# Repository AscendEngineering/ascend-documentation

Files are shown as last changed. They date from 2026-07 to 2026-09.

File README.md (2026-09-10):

# Ascend Engineering Documentation

Source for the Ascend Engineering documentation site, published at
**<https://docs.ascendengineer.com>**.

Built with [Material for MkDocs](https://squidfunk.github.io/mkdocs-material/) from
the Markdown in [`docs/`](docs/). Pushes to `main` auto-deploy via GitHub Pages.

## Products

- **[Ascend 8tof](docs/ascend-8tof/index.md)** — 360° time-of-flight
  obstacle-sensing system (up to 8× VL53L8CX sensors on an STM32H5 carrier board):
  hardware overview, power, the UART output protocol, firmware variants, and
  integration guides (with a VOXL2 worked example), a versioned firmware/installer
  download, and complete-assembly and electronics STEP files.

More products will be added as sibling sections under `docs/`.

## Local preview

```bash
python3 -m venv .venv && source .venv/bin/activate
pip install -r requirements.txt
mkdocs serve        # http://127.0.0.1:8000
```

## Contributing

Each product is a folder under `docs/` with its own `index.md`; add a matching
section to the `nav:` in `mkdocs.yml`. Keep customer-facing content only —
integration, usage, interfaces, and specs — not internal build/manufacturing
detail.

## Versioned downloads

The 8TOF [installer guide](docs/ascend-8tof/08-install-firmware.md),
[release notes](docs/ascend-8tof/09-firmware-release-notes.md), and
[case files](docs/ascend-8tof/10-case-files.md) are linked from the product nav.
Firmware ZIPs and CAD exports live under `docs/ascend-8tof/downloads/` so MkDocs
copies them to the deployed site. Keep the ZIP checksum paired with its exact
version. The reviewable installer source is in `tools/8tof-installer/` and must
match the files inside the downloadable ZIP.

The 10 Hz / 10 ms image is a bench candidate with hardware validation pending.
Do not remove that status until the exact image has been checked on hardware.
Per-board flash backups and local installation logs are not public assets.

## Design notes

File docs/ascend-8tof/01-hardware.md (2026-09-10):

# Hardware Overview

<figure markdown="span">
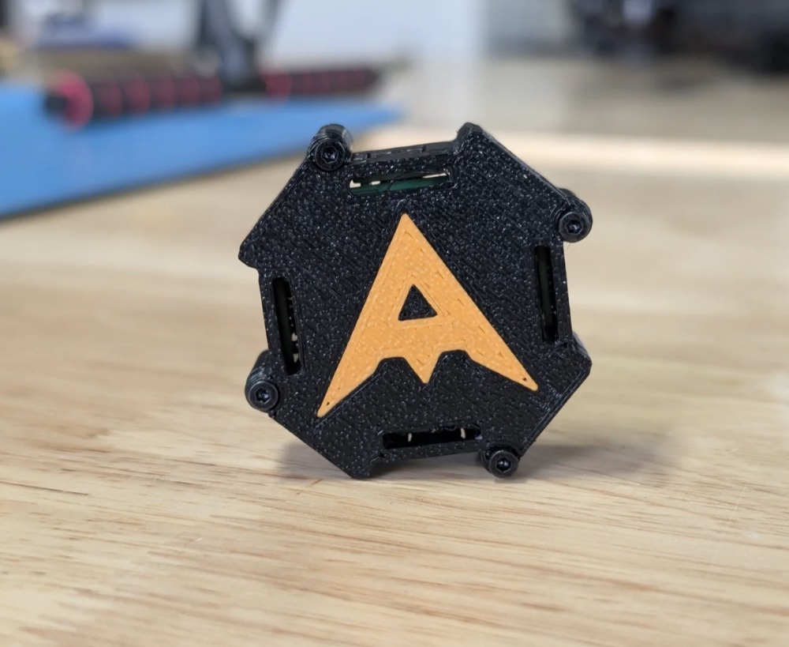
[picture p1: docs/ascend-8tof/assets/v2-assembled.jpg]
Assembled Ascend-8tof v2 in its printed case, Ascend "A" on the lid
  
  <figcaption>Assembled Ascend-8tof v2. The tip of the <strong>A</strong> marks the
  nose — the sensor behind the slot beneath it is <strong>CH7 (J8)</strong>.
  Each of the eight faces carries one VL53L8CX looking outward.</figcaption>
</figure>

The Ascend-8tof v2 is a **360° time-of-flight obstacle-sensing system** built from
two board types:

1. **Main / carrier board** — `oa_pcb_STM32H5_horizontal`, a 30 × 30 mm board
   carrying an **STM32H563RGT6**, a **TCA9548A** I²C multiplexer, onboard power
   regulation, a host UART and a SWD port.
2. **TOF sub-board (×8)** — one per channel, carrying a single **VL53L8CX** 8×8
   multizone ToF sensor. Eight plug into the main board to form the ring.

## Sensor at a glance

| Property | Value |
|---|---|
| Sensor | VL53L8CX multizone ToF |
| Zones per sensor | **8 × 8** (64 zones) |
| Sensors per board | **8** (360° coverage) |
| Ranging rate | Up to **15 Hz** at 8×8; the [candidate](09-firmware-release-notes.md) uses **10 Hz** |
| Range capability | **Up to 4 m** in suitable conditions; validate targets and lighting for the selected profile |
| Per-sensor field of view | ~45° per axis |

## Connectors & pinouts

Two externally-relevant connectors plus the eight sensor ports. **There is no
USB-C on v2** — `PA11`/`PA12` are unrouted, so all host traffic goes over `J5`.

| Connector | Type | Purpose |
|---|---|---|
| **`J5`** | JST GH 1.25 mm, 4-pin (SM04B-GHS-TB) | Power in **and** host UART |
| **`J6`** | JST GH 1.25 mm, 6-pin (SM06B-GHS-TB) | SWD — flashing and debug |
| **`J1`–`J4`, `J7`–`J10`** | 1.00 mm pin header, 1×05 | TOF sub-boards, one per channel |

<figure markdown="span">
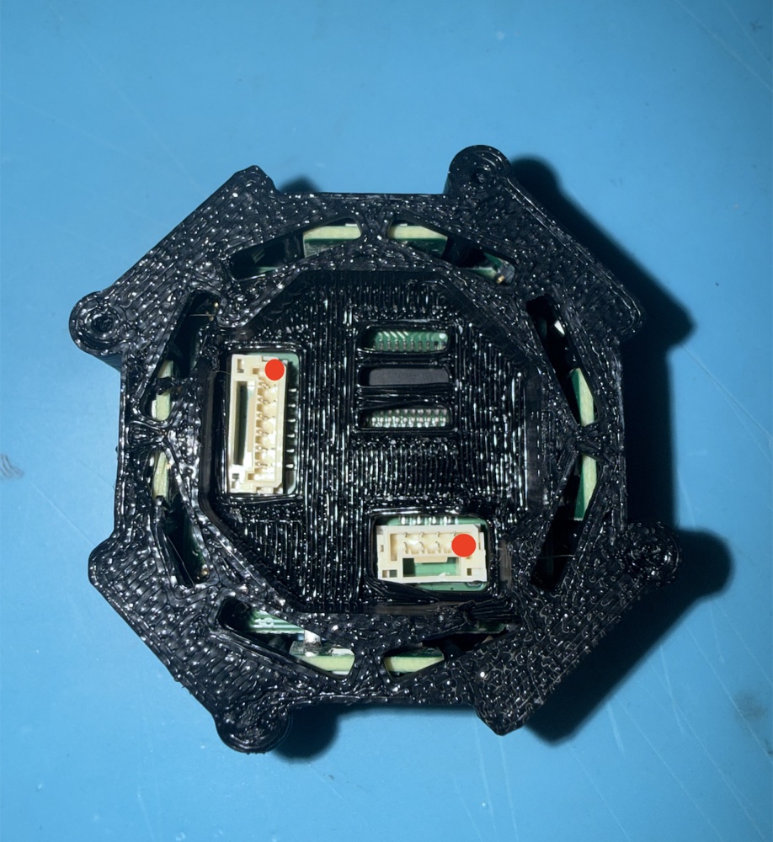
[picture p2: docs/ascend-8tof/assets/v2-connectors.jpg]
Underside of the assembled unit showing J6 (6-pin, upper left) and J5 (4-pin, lower right), each with its supply pin marked in red
  
  <figcaption>The two JST connectors, seen from the underside.
  <strong>J6</strong> (6-pin, upper left) and <strong>J5</strong> (4-pin, lower
  right). The <span style="color:#d33">red dots</span> mark the <strong>supply
  pin on each</strong> — <code>J5</code> pin 1 (<strong>VIN, 5 V</strong>) and
  <code>J6</code> pin 6 (+3V3). Use them to orient a cable before plugging it
  in: they are at opposite ends of the two connectors.</figcaption>
</figure>

**Power goes into `J5`** — the 4-pin connector, on the pin marked red. `J6` is
SWD; its +3V3 pin is a probe reference, not a way to power the board.

### `J5` — power + host UART

This single connector is both how you power the board and how you talk to it.

| Pin | Signal | Direction | Notes |
|-----|---|---|---|
| 1 | **VIN** | in | **5 V only** — see [Power](02-power.md) before wiring this |
| 2 | **RX** (`PA3`) | in | from your host's TX |
| 3 | **TX** (`PA2`) | out | to your host's RX |
| 4 | **GND** | — | must be common with the host |

!!! danger "Pin 1 is a regulated 5 V input, not a battery input"
    `J5` pin 1 feeds a 3.3 V LDO whose absolute maximum input is **6 V**, with no
    overvoltage protection in front of it. Anything above ~5.5 V risks destroying
    the board. See [Power](02-power.md).

### `J6` — SWD

| Pin | Signal |
|-----|---|
| 1 | GND |
| 2 | SWO |
| 3 | SWDIO |
| 4 | SWCLK |
| 5 | NRST |
| 6 | +3V3 |

Used for flashing firmware and for the SWD-readable diagnostics described in
[Bring-up & Setup](06-bringup-setup.md).

### Sensor connectors (×8) — 1.00 mm, 5-pin

All eight are identical. The sub-board's two supplies are generated on the
carrier board; you never provide them yourself.

| Pin | Signal |
|-----|---|
| 1 | +3V3 |
| 2 | +1V8 |
| 3 | SCL |
| 4 | SDA |
| 5 | GND |

Each connector is wired to one fixed TCA9548A channel, which fixes that
sensor's bearing in firmware:

| Channel | Connector | Bearing (CW from nose) | Direction |
|---|---|---|---|
| **CH7** | **`J8`** | **0°** | **FRONT / nose** |
| CH0 | `J4` | 45° | front-right |
| CH1 | `J3` | 90° | right |
| CH2 | `J2` | 135° | back-right |
| CH3 | `J1` | 180° | back |
| CH4 | `J9` | 225° | back-left |
| CH5 | `J10` | 270° | left |
| CH6 | `J7` | 315° | front-left |

!!! note "How the mapping is verified"
    The table above is confirmed two independent ways: the connector centroids in
    the PCB place the eight at 45° steps in the clockwise order
    `J8, J4, J3, J2, J1, J9, J10, J7`, and the TCA9548A netlist assigns its
    channel pin-pairs in the order `J4, J3, J2, J1, J9, J10, J7, J8` = CH0..CH7.
    Both agree with the physical build.

    Firmware's `tof8_sensor_bearing_deg[]` in `src/obstacle_avoidance.c` is the
    single source of truth — the browser configurator is served these exact
    values in its `INFO` message, so there is no second copy to keep in sync.

## Block diagram

```
                    ┌──────────────── carrier board (30 × 30 mm) ───────────────┐
   J5.1 VIN ──► D2 ─┼─► +5V ─► U3 ─► +3V3 ─┬─► IC1  STM32H563RGT6              │
   (5 V)      SS14  │        TLV75733      ├─► U2   TCA9548A ──┬── CH0  J4      │
                    │                      │                    ├── CH1  J3      │
   J5.2/3 UART ─────┼──── PA3 / PA2 ───────┘                    ├── ...          │
   J5.4 GND         │                                           └── CH7  J8 nose │
                    │        +3V3 ─► U1 ─► +1V8 ─► sensor pin 2                 │
   J6 SWD ──────────┼─────── TPS62130                                            │
                    └───────────────────────────────────────────────────────────┘
```

`IC1` reaches every sensor through `U2` on one I²C bus (`PB6` = SCL, `PB7` = SDA,
pulled up by `R2`/`R3`). Only one channel is connected at a time.

!!! note "U2's RESET is not under firmware control"
    `U2` pin 3 (`RESET`) connects only to pull-up `R6` — it is **not** wired to a
    GPIO. Firmware therefore cannot reset the multiplexer, and a channel
    selection can only be cleared by a **power cycle**. This matters when
    diagnosing a jammed bus; see
    [Bring-up → A sensor that jams the bus](06-bringup-setup.md#a-sensor-that-jams-the-bus).

## Dimensions & weight

| Item | Size |
|---|---|
| **Carrier board** | **30 × 30 mm** |
| **TOF sub-board** (each) | **8 × 7 mm** |
| **Assembled weight** (in case) | **15 g** |
| **Bare PCB weight** | **~9 g** |

## Mechanical / mounting

[Download the complete assembly and electronics STEP files](10-case-files.md) for
CAD reference, enclosure inspection, and mounting fit checks.

- Mount the unit flat, with the **tip of the "A" on the case lid facing the
  vehicle nose**. That puts **CH7 (`J8`) at 0°**, and the other seven follow
  clockwise at 45° steps.
- Getting this wrong rotates the entire obstacle picture, so confirm it before
  flying: open the [configurator](https://tools.ascendengineer.com), wave a hand
  at the nose, and check that **CH7**'s grid is the one that lights up.
- Sensors sit close to the vehicle centre, so mounting translation is negligible
  at meter-scale avoidance; the rotations are what matter. See
  [Integration](05-integration.md).

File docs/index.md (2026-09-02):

# Ascend Engineering Documentation

Technical documentation for Ascend Engineering hardware and software —
UAV companion computers, sensor systems, firmware, and integration guides.

<div class="grid cards" markdown>

-   :material-radar: **Ascend 8tof v2**

    ---

    360° time-of-flight obstacle-sensing system — a 30 × 30 mm STM32H563 carrier
    board reading 8× VL53L8CX sensors and emitting **MAVLink
    `OBSTACLE_DISTANCE`** straight into **stock PX4 collision prevention**, plus
    a binary 512-zone point cloud on request. Hardware, pinouts, power, comms,
    firmware, and integration (with a VOXL2 worked example).

    [:octicons-arrow-right-24: Open the Ascend 8tof docs](ascend-8tof/index.md)

-   :material-cube-outline: **More coming**

    ---

    Additional hardware and software documentation will live here as it's
    written — each product gets its own section in the left-hand navigation.

</div>

## About this site

- Every product has its own section in the sidebar (and top tabs); pick a
  product above or from the navigation to dive in.
- Documentation is maintained in the
  [`ascend-documentation`](https://github.com/AscendEngineering/ascend-documentation)
  repository; pushes to `main` auto-deploy to this site.

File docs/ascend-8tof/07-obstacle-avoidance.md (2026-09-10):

# Obstacle Avoidance — Onboard VFH + PX4 Setpoint Fusion

!!! warning "This is the `AVOID=vfh` path — not the default"
    The **default v2 firmware is `AVOID=cp`**, which emits `OBSTACLE_DISTANCE`
    into **stock PX4** and needs no custom autopilot. Start with
    [Integration](05-integration.md).

    Everything on this page requires the **Ascend PX4 fork**. Use it only if you
    need avoidance in **Mission mode**, which stock collision prevention does not
    provide.

This page explains an alternative avoidance approach for the Ascend-8tof: the board runs
the avoidance planner **on-board**, computes the *best evasive motion itself*, and
**streams velocity setpoints** to a **PX4 flight controller** that has been
extended to accept and blend them during normal flight. The drone steers around
obstacles while a mission or the pilot stays in control.

!!! note "Where this sits vs. the other firmware"
    | Approach | Who decides the maneuver | Talks to FC as | Avoids in |
    |----------|--------------------------|----------------|-----------|
    | **`AVOID=cp`** (default) | PX4 | `OBSTACLE_DISTANCE` (#330) → stock PX4 collision prevention (brake/deflect) | Position mode |
    | **`AVOID=vfh`** (this page) | The board (VFH) | `SET_POSITION_TARGET` (#84) → **forked PX4** (fuse & steer) | **Position *and* Mission** |
    | Raw point cloud | Your host | binary 512-zone frames | up to you |

    The key difference from `AVOID=cp`: instead of feeding PX4 raw obstacle distances and
    letting *its* built-in logic brake, the board computes the **actual escape
    velocity** and PX4 just executes it. This works in **Mission mode too**.

---

## The idea in one picture

```
 Ascend-8tof (STM32H5)                                   PX4 (Ascend fork)
 ─────────────────────                                   ──────────────────
 8× VL53L8CX  ─► point cloud (body frame)
                72-sector polar histogram (VFH)
                pick the best open gap
                     │                                    ┌──────────────────────┐
   path blocked? ────┤ yes ─► velocity setpoint ─MAVLink─►│ accept + FUSE the     │
                     │        SET_POSITION_TARGET  (UART)  │ setpoint in Position/ │─► drone
                     │        (#84, BODY_NED)              │ Mission mode          │   deviates
                     └ no ──► send nothing ───────────────►│ setpoint goes stale → │─► resumes
                                                           │ mission/pilot resumes │   course
   ◄── ODOMETRY (velocity/attitude) ─────────────────────  └──────────────────────┘
```

The board only speaks up **while an obstacle is in the way**. When the path is
clear it goes silent, PX4's fusion times out, and the vehicle simply carries on
with whatever it was doing — a **temporary deviation**, not a takeover.

---

## Why a forked PX4?

Stock PX4 **only accepts external `SET_POSITION_TARGET` setpoints in Offboard
mode** — a full-authority mode with no mission or pilot in the loop. That's not
what we want: we want the mission (or the pilot) to stay in charge and only be
*nudged* around obstacles.

So Ascend maintains a small PX4 fork that adds one capability: **accept an
external avoidance setpoint and fuse it into Position and Mission mode.** It's a
narrow, surgical change:

- A new uORB topic (`external_avoidance_setpoint`) carries the incoming velocity.
- The MAVLink receiver mirrors an incoming `SET_POSITION_TARGET_LOCAL_NED` onto it.
- At the single point where **both** manual (Position) and auto (Mission) flight
  tasks produce their setpoint, the fork blends the external velocity in — and
  NaNs the matching position axis so the position controller doesn't fight the
  deviation.

The board owns *all* the intelligence (sensing + planning). PX4's only job is to
**accept and blend**. If the external stream stops, PX4 reverts instantly.

---

## What the board computes (VFH)

The avoidance planner is a **Vector Field Histogram** running on the STM32 — the
same algorithm whether it's flying the real vehicle or being tested in sim:

1. **Point cloud** — the 8× 8×8 ToF grids become 3-D points in the vehicle body
   frame (roll/pitch compensated from FC attitude; floor/ceiling returns rejected).
2. **Polar histogram** — points are binned into **72 sectors** (5° each) holding
   the nearest obstacle per direction.
3. **Gap selection** — if the direction of travel is blocked, it finds the
   nearest wide-enough open gap (with hysteresis so it doesn't dither).
4. **Setpoint** — it emits a **velocity toward that gap** (default: a lateral
   *strafe* that holds heading for the fastest clearance; an optional
   *steer-to-gap* variant turns the nose instead).

This is **reactive** (no global map) and **horizontal** — ideal for "don't hit
the thing in front of me," and light enough to run on the MCU.

---

## Flight behavior

=== "Position mode"
    The pilot flies normally. When they command motion toward an obstacle, the
    board's setpoint **deflects** that motion around it. Hands-off, the drone
    simply holds — there's no goal beyond the obstacle to continue toward, so
    avoidance is naturally coupled to the pilot commanding movement.

=== "Mission mode"
    The vehicle flies its waypoints. When an obstacle blocks a leg, the board
    steers around it; the moment the path clears, PX4 resumes flying **straight
    to the active waypoint** from wherever it ended up. The mission is never
    interrupted — Ascend's fork does the deviation, PX4's navigator keeps the goal.

!!! info "After it clears the obstacle"
    The vehicle **continues on a new straight line** — to the waypoint (Mission)
    or in the pilot's commanded direction (Position). It does **not** retrace the
    exact original track; there's no cross-track "return to line" step (that's an
    optional future addition).

---

## Interface & configuration

**On the wire (board → FC):** `SET_POSITION_TARGET_LOCAL_NED` (#84),
`MAV_FRAME_BODY_NED`, velocity (± yaw-rate) active, ~20 Hz, streamed **only while
avoiding**. Same UART link as the other MAVLink firmware.

**The FC also streams back** `ODOMETRY` (#331) so the board knows the vehicle's
velocity (its "direction of travel") and attitude.

**PX4 parameters** (on the Ascend fork):

| Parameter | Default | Meaning |
|---|---|---|
| `EAV_EN` | `0` (off) | Enable fusion of the external avoidance setpoint |
| `EAV_TIMEOUT` | `0.5 s` | If no setpoint arrives within this, fusion stops and the mission/pilot setpoint resumes |

The MAVLink instance reading the board's UART must have **`forward_externalsp`
enabled** (PX4 only processes `SET_POSITION_TARGET` with it on).

---

## How it's validated — a "digital twin"

The simulation workflow exercises the firmware avoidance code in **Gazebo**:

- A simulated drone carries **8 modelled ToF sensors** (8×8, 45° FoV, 4 m).
- A bridge process **runs the real firmware algorithm unchanged**, fed by the
  simulated sensors, and streams `SET_POSITION_TARGET` to a PX4 SITL running the
  fork — the same data path as the real vehicle. Only the I/O differs (sim topics
  instead of I²C, UDP instead of UART).

The bridge uses the on-board algorithm to tune and regression-check avoidance.
Simulation results apply to the code and scenarios tested; they do not establish
physical sensor range or validate a different firmware revision. See the
[release validation status](09-firmware-release-notes.md#validation-status) for
the downloadable 10 Hz / 10 ms candidate.

---

## Status

!!! warning "In active development"
    Setpoint-streaming avoidance and the PX4 fork are **in active development**.
    Reactive/horizontal only; earlier versions were exercised in simulation and
    early flight. Start with the default **`AVOID=cp` integration** and read the
    [candidate validation status](09-firmware-release-notes.md#validation-status)
    before choosing a firmware version. Validate setpoint fusion separately on
    the intended vehicle.

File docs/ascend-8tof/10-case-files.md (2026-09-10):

# Case and assembly files

Download the v2 complete-assembly and electronics STEP files for enclosure fit
checks, mounting, and CAD reference. Both exports are preserved as supplied.
The electronics STEP replaces the previously supplied assembly STL download.

| Download | Format | Size | Intended use |
|---|---|---|---|
| [Complete assembly — STEP](downloads/case/tof8_v2_COMPLETE_assembly.step) | STEP / AP214 | 7.34 MiB | Inspect the complete assembly and select enclosure components |
| [Electronics assembly — STEP](downloads/case/tof8_v2_electronics.step) | STEP / AP214 | 4.19 MiB | Inspect the electronics assembly and check enclosure clearances |
| [File checksums](downloads/case/SHA256SUMS) | SHA-256 | — | Confirm downloads match the supplied exports |

Assembled v2 case with the forward-facing A

The tip of the **A** on the lid faces the vehicle nose, aligned with **CH7/J8**.
Use the [hardware overview](01-hardware.md#mechanical-mounting) for connector
orientation and the [bring-up guide](06-bringup-setup.md) to verify it with a
real target.

## Using the files

- Both STEP files declare **millimetres** and contain multiple solids. Import
  them as assembly/reference models; check your CAD program's unit settings.
- Use the complete-assembly export to inspect the case and select the enclosure
  components you need. Use the electronics export to reference board and
  component placement when checking clearances.
- Select and export individual enclosure pieces for your slicer before preparing
  a print. These downloads do not include verified print orientation, supports,
  tolerances, or material settings.

Both STEP headers/terminators, unit declarations, and checksums were checked.
These checks establish file integrity; mechanical fit and print readiness still
require inspection and a physical fit check. The documentation update does not
modify either file's geometry.

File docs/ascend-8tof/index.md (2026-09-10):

# Ascend-8tof v2 — System Documentation

Documentation for the **Ascend-8tof v2** 360° time-of-flight obstacle-sensing
system: a 30 × 30 mm carrier board (STM32H563) reading **8× VL53L8CX** 8×8
multizone ToF sensors and speaking **MAVLink** to a flight controller over a
single UART.

```
 8× VL53L8CX ──► carrier board ──┬── MAVLink OBSTACLE_DISTANCE ──► PX4 collision prevention
  (8×8 grids)   (mux + STM32H5)  │   (always on)
                                 └── 512-zone point cloud ──────► configurator / your host
                                     (on request)
```

## Downloads

- [Firmware and installer](08-install-firmware.md) — 10 Hz / 10 ms bench candidate;
  read the [validation status](09-firmware-release-notes.md#validation-status).
- [Case and assembly STEP files](10-case-files.md).

## Documentation map

| # | Document | Contents |
|---|---|---|
| 01 | [Hardware Overview](01-hardware.md) | Board, connectors & pinouts, channel map, mounting |
| 02 | [Power](02-power.md) | Input voltage limits and how to power it |
| 03 | [Communications](03-comms-protocol.md) | MAVLink output and the binary point-cloud link |
| 04 | [Firmware](04-firmware.md) | Build variants, flashing, diagnostic builds |
| 05 | [Integration](05-integration.md) | PX4 collision prevention + VOXL2 worked example |
| 06 | [Bring-up & Setup](06-bringup-setup.md) | Assemble → power → verify → integrate → troubleshoot |
| 07 | [Obstacle Avoidance (onboard VFH)](07-obstacle-avoidance.md) | The alternative `AVOID=vfh` path, needing the Ascend PX4 fork |
| 08 | [Install Firmware](08-install-firmware.md) | Prebuilt download, ST-Link setup, installer, and rollback |
| 09 | [Firmware Release Notes](09-firmware-release-notes.md) | 10 Hz / 10 ms candidate, measurement behavior, validation status |
| 10 | [Case & Assembly Downloads](10-case-files.md) | Complete assembly and electronics STEP exports |

## Key facts at a glance

- **Sensors:** 8× VL53L8CX, each an **8×8 zone grid**, configurable up to **15 Hz**, forming a 360° ring.
- **Range capability:** up to 4 m under suitable conditions; usable range depends
  on lighting, target, and profile. ~45° field of view per axis.
- **Power:** **5 V only** on `J5` pin 1; current depends on the ranging profile — see [Power](02-power.md).
- **Host link:** one UART at **921 600 8N1** carrying MAVLink (always) and the
  point cloud (on request).
- **Default output:** `OBSTACLE_DISTANCE` (#330) at 10 Hz, 72 bins × 5°, straight
  into **stock PX4 collision prevention** — no custom autopilot build.
- **Mounting:** the tip of the **A** on the lid is the nose = **CH7 (`J8`)**.
- **Configurator:** <https://tools.ascendengineer.com> — live 3D cloud and zone
  masking in Chrome.

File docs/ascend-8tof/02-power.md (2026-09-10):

# Power

v2 takes a **single 5 V input** on `J5` pin 1 and generates the sensor rails
on-board. You never supply sensor voltages yourself.

!!! danger "5 V only"
    There is **no wide-input regulator.** `J5` pin 1 feeds a 3.3 V LDO directly
    through a series Schottky diode. Wiring a flight battery to it will destroy
    the board.

## Input

| Parameter | Value |
|---|---|
| **Input voltage** | **5 V nominal** |
| **Maximum** | **~5.5 V** — see the limit below |
| Connector | `J5` pin 1 (JST GH 1.25 mm, 4-pin) — [which pin, in a photo](01-hardware.md#connectors-pinouts) |
| Ranging current | Profile and load dependent; measure at the regulated 5 V input |
| Peak current | brief inrush at power-on as all eight sensors initialise |
| Protection | **reverse polarity only** (`D2`, SS14 Schottky in series) |

### Where the limit comes from

The supply chain is short and has no headroom above 5 V:

```
J5.1 ──► D2 (SS14, series Schottky) ──► +5V ──► U3 (TLV75733) ──► +3V3
                                                                    │
                                                                    └─► U1 (TPS62130) ──► +1V8
```

`U3` is a **TLV75733** 3.3 V LDO whose input is rated **5.5 V recommended,
6 V absolute maximum**. Nothing upstream of it clamps or regulates — `D2` is a
plain series diode that only blocks reverse polarity and drops roughly 0.3–0.4 V.
So the LDO sees very nearly whatever you apply to `J5` pin 1.

`U1` (TPS62130) is a wide-input buck, but it is **not** the input stage: it runs
from the 3.3 V rail to produce the sensors' 1.8 V. It does not protect the input.

!!! warning "There is no overvoltage protection"
    `D2` blocks reverse polarity and nothing else — any positive voltage passes
    straight through to a 6 V-max part. This is a known limitation of the current
    revision and is on the list for the next one. Until then, **feed `J5` from a
    regulated 5 V rail**, and check with a meter before plugging in an unfamiliar
    supply.

## Powering it

| Situation | How |
|---|-----|
| **Bench** | A USB-UART adapter's 5 V/VCC pin into `J5` pin 1, with its TX/RX/GND on pins 2/3/4. One cable does power and data. |
| **On a vehicle** | A regulated **5 V** rail from the flight-control unit or power module into `J5` pin 1. |

Because `J5` carries power and UART on the same connector, a single 4-wire lead
is all the integration needs. See [Bring-up & Setup](06-bringup-setup.md).

## What the board provides

- Both sensor supplies (**+3V3** and **+1V8**) are generated on-board and
  distributed through the eight sensor connectors.
- `J6` pin 6 is **+3V3**. It is there so a debug probe can sense target voltage —
  do not use it to power the board.

## Choosing a ranging profile

The [10 Hz / 10 ms candidate](09-firmware-release-notes.md) collects more light
per measurement than the earlier 15 Hz / 5 ms experiment, at a longer frame
interval. An 8×8 frame uses four sub-integrations:

| Profile | Exposure per frame | Calculated exposure duty |
|---|---:|---:|
| 15 Hz / 5 ms | 20 ms | 30% |
| **10 Hz / 10 ms candidate** | **40 ms** | **40%** |
| 15 Hz / 10 ms | 40 ms | 60% |

Exposure duty is not total board power. Sensor processing, MCU activity, the
UART stream, and losses in the input diode and 3.3 V LDO also contribute.
Keep voltage, connected peripherals, and scene fixed when comparing input
current/watts. Check reliable detections at known distances indoors and in
daylight; dashboard frame rate alone does not establish range or accuracy.

The candidate's power and range have not yet been measured. Shortening
integration can save power but makes weak reflections harder to detect.
[ST integration timing](https://www.st.com/content/st_com/en/technical-documents/UM3109.html).

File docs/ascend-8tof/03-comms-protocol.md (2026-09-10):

# Communications — UART Protocols

`J5` is v2's only host connector, and it carries **two protocols at once** at
**921 600 baud, 8N1**:

| Protocol | Direction | When it runs |
|---|---|---|
| **MAVLink v2** | board → host (and host → board) | **always, unconditionally** |
| **Point-cloud link** (`0xA5 0x5A` framed) | board → host, on request | **only while a host asks for it** |

## Why a passive listener sees only MAVLink

This is the single most common surprise on v2, and it is deliberate.

`J5` is the board's only UART, so it has to serve both the flight controller and
the configurator. Rather than a mode switch — which could leave a vehicle flying
with avoidance disabled if it ever got stuck — **MAVLink always runs**, and only
the high-rate point cloud is gated:

- Any valid point-cloud command received from a host **arms** streaming and
  refreshes a deadline (`UART_LINK_GATE_MS`, 3 s).
- When the host stops talking, the deadline lapses and the cloud stops on its own.
- **At boot the gate is shut.**

So on the bench with a configurator attached you get the full cloud, and in
flight with nothing attached the link carries only MAVLink. Avoidance is never
suspended either way.

**The practical consequence:** you cannot sniff the point cloud. You have to ask
for it and keep asking, roughly once a second. If you are seeing MAVLink and no
`0xA5 0x5A` frames, that is the gate, not a fault.

Receive needs no gating — the USART2 interrupt mirrors every incoming byte to
both parsers, and each ignores what it does not recognise (MAVLink syncs on
`0xFD`, the point-cloud link on `0xA5 0x5A`, and both are CRC-checked).

## MAVLink output

What the board emits depends on the firmware variant (see
[Firmware](04-firmware.md)):

| Message | ID | Rate | Variant |
|---|-----|---|---|
| `HEARTBEAT` | 0 | 1 Hz | all |
| `OBSTACLE_DISTANCE` | **330** | **10 Hz** | `AVOID=cp` (default) |
| `SET_POSITION_TARGET_LOCAL_NED` | 84 | — | `AVOID=vfh` |

The board also *parses* `ODOMETRY` (331) and `ATTITUDE_QUATERNION` (31) coming
back from the flight controller, and uses the attitude for tilt compensation.

### `OBSTACLE_DISTANCE` field values

These values describe the [10 Hz / 10 ms candidate](09-firmware-release-notes.md).
Older firmware can use different minimum-range and unknown-data behavior;
confirm the installed version before relying on these semantics.

| Field | Value |
|---|---|
| `frame` | `MAV_FRAME_BODY_FRD` (12) |
| `sensor_type` | `MAV_DISTANCE_SENSOR_LASER` (0) |
| `increment_f` | **5.0°** |
| `angle_offset` | **2.5°** (bin centres, not edges) |
| `distances[]` | **72 bins**, centimetres |
| `min_distance` | **2 cm** in the candidate (older builds used 50 cm) |
| `max_distance` | **400 cm** |

Two sentinel values matter:

- **`401` (`max_distance + 1`)** means no obstacle within the advertised range.
  The candidate does **not** generate this from a missing echo or geometric
  coverage alone.
- **`65535` (`UINT16_MAX`)** means **unknown / not used**. The candidate uses it
  for weak, missing, masked, expired, and unmeasured directions.

An accepted measurement provides an obstacle distance, with the nearest return
winning in each bin. Samples expire 200 ms after their successful polling pass.
PX4 may restrict motion into unknown directions; do not enable `CP_GO_NO_DATA`
merely to hide missing measurements. The 400 cm field is the configured maximum,
not a guarantee of reliable 4 m detection under every lighting/target condition.

## Point-cloud link

The binary protocol the browser configurator speaks, carrying the **raw,
unmasked** 512-zone cloud plus the read/write path for the persistent zone mask.

### Framing

```
0xA5 0x5A  <type:u8>  <len:u16 LE>  <payload[len]>  <crc16:u16 LE>
```

CRC-16/MCRF4XX ("X.25") over `type + len + payload`. The two-byte sync word plus
the CRC lets a host that connects mid-stream resynchronise unambiguously, and
lets it skip the interleaved MAVLink bytes.

### Message types

| Direction | ID | Name | Payload |
|---|-----|---|---|
| board → host | `0x01` | `INFO` | geometry: sensor count, grid size, per-channel bearings, mask sequence |
| board → host | `0x02` | `FRAME` | the full 512-zone cloud (below) |
| board → host | `0x03` | `MASK` | current 512-byte zone mask |
| board → host | `0x04` | `ACK` | reply to a host command |
| board → host | `0x05` | `DIAG` | why bring-up failed, per channel |
| host → board | `0x81` | `GET_INFO` | — |
| host → board | `0x82` | `GET_MASK` | — |
| host → board | `0x83` | `SET_MASK` | 512 gate bytes (RAM only) |
| host → board | `0x84` | `SAVE_MASK` | persist RAM mask to flash |
| host → board | `0x85` | `STREAM` | `u8` enable |
| host → board | `0x86` | `GET_DIAG` | — |

Any of the host → board messages re-arms the 3 s gate, so `GET_INFO` doubles as
a keepalive.

### `FRAME` payload

1554 bytes: an 18-byte header followed by eight fixed-size sensor blocks.

| Offset | Size | Field |
|---|---|---|
| 0 | u32 | `seq` |
| 4 | u32 | `timestamp_ms` |
| 8 | u8 | `sensor_valid` — bit *n* = channel *n* has data this frame |
| 9 | u8 | `odom_valid` |
| 10 | i16 | `roll_cdeg` |
| 12 | i16 | `pitch_cdeg` |
| 14 | i16 | `yaw_cdeg` |
| 16 | u16 | reserved |
| 18 | 8 × 192 | per-sensor block |

Each sensor block is **64 little-endian u16 ranges in mm**, then **64 status
bytes**. Channels with no data are sent as zeroes so the payload stays
fixed-size and a host can index it without parsing.

!!! note "Only status 5 and 9 are real measurements"
    Every other status is a no-return. Treat those zones as **no data** — never
    as "obstacle at 0 mm". `FRAME` deliberately carries the *unmasked* cloud so
    the configurator can show you what a mask would discard; everything
    downstream of this link (the planner, the MAVLink output) sees the masked
    cloud.

## Reading it

The supported tools live in the firmware repo:

```bash
# stream the raw 8×(8×8) matrices — handles the keepalive for you
python3 tools/tof8-stream.py                        # live grids
python3 tools/tof8-stream.py --format jsonl         # one JSON object per frame
python3 tools/tof8-stream.py --format csv -o cloud.csv

# link health / which channels are ranging
python3 tools/tof8-poll.py
```

Both are standard-library only (no `pyserial`) and run on Python 3.6, so they
work on a stock VOXL2 image.

!!! warning "One process owns the port"
    A serial port has one owner. If the configurator tab, `screen`, or
    `mavlink-router` holds `J5`, these tools cannot. On a VOXL2, `/dev/ttyHS1` is
    already owned by PX4's `mavlink` instance — two readers on one tty do not each
    get a copy, they race and both get a corrupted subset. `tof8-stream.py` warns
    when another process already holds the device.

## Graphical configurator

<https://tools.ascendengineer.com> — a browser tool (Chrome, via Web Serial) that
draws the live cloud in 3D and lets you paint and save the zone mask. It speaks
exactly the protocol above and keeps the gate open with a ~1 Hz keepalive.

Web Serial requires a **secure context**, so the tool must be loaded over HTTPS.

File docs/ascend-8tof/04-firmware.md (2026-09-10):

# Firmware

## Prebuilt firmware and installer

The [2026.09.10-10hz10ms download](08-install-firmware.md) is a **bench candidate**
for the horizontal v3 carrier with eight v2 sensor boards. It uses 8×8 zones,
10 Hz per sensor, 10 ms sub-integration, `AVOID=cp`, and 180° zone orientation.
It also corrects weak/invalid readings being reported as clear space.

The package includes its installer and offline instructions. No source checkout
or compiler is needed. Read the [release notes](09-firmware-release-notes.md)
and [pending hardware-validation status](09-firmware-release-notes.md#validation-status)
before using it.

## Source builds

The firmware codebase is
[`AscendEngineering/ascend-8tof`](https://github.com/AscendEngineering/ascend-8tof).
Source builds select a board variant and an avoidance output. Use the versioned
package for the candidate above; a checkout of the firmware repository is not
proof that it contains every change in that prebuilt image.

```bash
make BOARD=horiz3 AVOID=cp          # source default profile; not the versioned candidate installer
```

## Board variant — `BOARD=`

Always build with **`BOARD=horiz3`** (`oa_pcb_STM32H5_horizontal`). It selects the
single-UART configuration: `J5` carries MAVLink *and* the gated point cloud.

!!! warning "`BOARD=` does not default to this board"
    The Makefile's default targets a different variant, so omitting `BOARD=horiz3`
    silently builds an image that will not work here. Pass it every time — or use
    `tools/flash-board.sh`, which sets it for you.

## Avoidance output — `AVOID=`

This selects what goes on the MAVLink wire. The point-cloud link is unaffected.

| Value | Emits | Who avoids | Requires |
|---|---|---|---|
| **`cp`** (default) | `OBSTACLE_DISTANCE` (#330) at 10 Hz | **stock PX4** collision prevention | `CP_DIST > 0` on the FC |
| `vfh` | `SET_POSITION_TARGET_LOCAL_NED` (#84) | the **board**, running VFH+ | the Ascend PX4 fork |
| `both` | both | — | bench comparison only |

!!! warning "`AVOID=both` is not a flight configuration"
    On a fork that honours #84, the two controllers fight over the same axis.
    Use it to compare behaviour on the bench, never on a vehicle.

`AVOID=cp` is the one to use unless you are specifically working on the fork —
it needs no custom PX4. See
[Obstacle Avoidance](07-obstacle-avoidance.md) for the `vfh` path and
[Integration](05-integration.md) for the `cp` path.

## Diagnostic and repair builds

These exist for bring-up and board repair. They are not flight builds.

| Option | Purpose |
|---|---|
| `DIAG=1` | Cold-boot I²C bus walk — finds a sensor that jams the bus |
| `DIAG=1 DIAGDIR=down` | The same walk in descending channel order |
| `EXCLUDE=4` | Permanently skip mux channel 4 (comma-separate for several) |

`EXCLUDE=` can isolate a known-bad sensor during diagnosis: the excluded
channel is never selected, so one failed part cannot take the other seven down
with it. See
[Bring-up → A sensor that jams the bus](06-bringup-setup.md#a-sensor-that-jams-the-bus).

Each combination builds into its own directory (`build/horiz3-cp`,
`build/horiz3-cp-ex4`, …) so a diagnostic image is never mistaken for a flight
image.

## Flashing

For the downloadable candidate, follow [Install Firmware](08-install-firmware.md).
It checks package integrity, backs up flash, verifies the image and sensor
profile, and checks saved masks. The commands below are the firmware
repository's older source-build workflow, not the packaged installer.

v2 has no USB and no bootloader button — **firmware goes on over SWD** via `J6`
with an ST-Link.

```bash
AVOID=cp BOARD=horiz3 ./tools/flash-board.sh
```

The script identifies the chip, flashes, waits for bring-up and prints the
per-channel result:

```
firmware  : build/horiz3-cp/ascend-horiz3-fw.elf
board UID : 00520036
** Programming Finished **
** Verified OK **
uptime    : 12.6 s
sensors   : 8/8
result    : ALL 8 CHANNELS OK
```

!!! note "A reset is not a power cycle"
    The script's post-flash reading happens after a **reset**, which does not
    clear the TCA9548A's channel latch. A board whose bus was jammed before
    flashing will still report `0/8` afterwards even if it is fine. Power-cycle
    it and re-check with `./tools/read-sensors.sh`, which reads a running board
    without resetting it.

## Ranging and measurement behavior

- The sensors support up to **15 Hz** at 8×8; older builds use that rate. The
  downloadable candidate explicitly selects **10 Hz / 10 ms**.
- The persistent zone mask applies to avoidance processing. The browser receives
  the raw cloud so users can see and edit the returns being excluded.
- `AVOID=cp` sends `OBSTACLE_DISTANCE` at 10 Hz, independently of the sensor
  rate. A faster browser packet counter is not a faster sensor measurement rate.
- The candidate reports weak, missing, masked, expired, and unmeasured directions
  as **unknown**. It retains close valid obstacles instead of discarding all
  measurements below 50 cm, and expires cached samples after 200 ms.
- Initialization retries and per-channel recovery exist in the source. The
  candidate reapplies its selected profile during recovery; physical recovery
  fault injection remains unverified. A stuck I²C bus can still require a
  power cycle or hardware repair.

See [release notes](09-firmware-release-notes.md) for the exact changes and
validation limits. These descriptions do not imply every older board already
has the candidate installed.

## Persistent zone mask

Zones can be permanently excluded — propellers, landing gear, the vehicle's own
frame. The mask is painted in the [configurator](https://tools.ascendengineer.com)
and saved to flash with `SAVE_MASK`.

It is stored in the **last two 8 KB sectors of bank 2** as alternating A/B slots
with a CRC and a sequence number, so an interrupted write can never destroy the
config currently in use. Firmware loads it before the first frame is served.

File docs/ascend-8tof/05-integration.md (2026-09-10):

# Integration

With the default `AVOID=cp` firmware, v2 speaks **stock MAVLink** to a stock
PX4. There is no plugin to install and no custom autopilot build: the board
emits `OBSTACLE_DISTANCE` (#330) and PX4's built-in collision prevention does
the avoiding.

## Wiring

| Board | Host |
|---|---|
| `J5` pin 3 (TX) | host RX |
| `J5` pin 2 (RX) | host TX |
| `J5` pin 4 (GND) | host GND |
| `J5` pin 1 | regulated **5 V** |

Both data directions must be connected. The board needs attitude back from the
flight controller for tilt compensation, and the point-cloud link is gated on
hearing from a host at all.

## PX4 collision prevention

### 1. Give PX4 a MAVLink instance on that port

The board sends #330 at 10 Hz and needs `ODOMETRY` back. On a VOXL2, add this to
`/usr/bin/voxl-px4-start` **before** `mavlink boot_complete`:

```bash
# 8TOF obstacle array on /dev/ttyHS1. Sends OBSTACLE_DISTANCE (#330) for PX4
# collision prevention, and needs attitude back for tilt compensation.
# -m minimal, not onboard: the board only parses ODOMETRY (#331) and
# ATTITUDE_QUATERNION (#31), so a full onboard stream set is wasted bandwidth.
mavlink start -d /dev/ttyHS1 -b 921600 -m minimal -r 2000
mavlink stream -d /dev/ttyHS1 -s ODOMETRY -r 30
```

On other autopilots, point any spare TELEM port at the board at **921 600** and
make sure `ODOMETRY` is streamed back.

### 2. Set the parameters

| Parameter | Value | Why |
|---|---|-----|
| `CP_DIST` | **> 0** (e.g. `1.5`) | Gates collision prevention entirely. At `-1` it is off and nothing else matters. |
| `MPC_POS_MODE` | **see below** | Determines whether the active flight task even *has* collision prevention. |
| `CP_GO_NO_DATA` | `0` (default) | Whether to allow movement into bins with no data. |

!!! danger "`MPC_POS_MODE` depends on your PX4 version"
    Collision prevention lives in a different flight task depending on release,
    and setting the wrong one produces a vehicle that flies happily through
    obstacles with no error message:

    | PX4 | Where CP lives | Working `MPC_POS_MODE` |
    |-----|----------------|------------------------|
    | **1.14** | `FlightTaskManualPosition` (and `…SmoothVel`) | **3** |
    | **1.18** | `StickAccelerationXY` | **4** |

    On 1.14, `MPC_POS_MODE=4` selects `FlightTaskManualAcceleration`, whose
    `StickAccelerationXY` has **no** collision prevention at all. Check the
    firmware version on the vehicle before trusting any guide — including this
    one.

Collision prevention is **position-mode only**. It does not act in altitude or
manual mode, and mission avoidance is a separate feature.

### 3. Verify PX4 is receiving it

```bash
listener obstacle_distance
```

You want a recent timestamp and a populated `distances` array. `never published`
means the messages are not arriving — check baud, wiring direction, and that the
`mavlink` instance is actually running on that device.

On a VOXL2 note the split architecture: `mavlink` runs on the **apps processor**
while `commander`, `flight_mode_manager` and `mc_pos_control` run on the **SLPI
DSP**. The topic crosses a `muorb` bridge, so check the subscriber count on the
DSP side too — a topic published on apps with zero DSP subscribers will look
alive and still do nothing.

### What "clear" and "unknown" mean

For the [10 Hz / 10 ms candidate](09-firmware-release-notes.md):

- **`401` cm** is the MAVLink value for no obstacle within the advertised range.
  The candidate does not infer it from a missing echo.
- **`65535`** is unknown, including weak/no-target returns, masked zones,
  expired samples, and unmeasured directions.
- Other accepted values are measured obstacle distances. Valid close returns
  are retained, including those below the older firmware's 50 cm cutoff.

Unknown can cause PX4 Collision Prevention to restrict movement. Do not set
`CP_GO_NO_DATA` merely to bypass missing measurements. Validate the installed
firmware's behavior with real targets before using it for collision prevention.
See [wire fields](03-comms-protocol.md#obstacle_distance-field-values).

## Reading the raw cloud on a host

If you want the 512-zone cloud rather than (or as well as) avoidance:

```bash
python3 tools/tof8-stream.py --format jsonl     # one JSON object per frame
python3 tools/tof8-stream.py --format csv -o cloud.csv
```

Standard library only, Python 3.6+, so it runs on a stock VOXL2 image. See
[Communications](03-comms-protocol.md#point-cloud-link) for the wire format if
you are writing your own parser.

!!! warning "You cannot share the port with PX4"
    A tty has one owner. If PX4's `mavlink` holds `/dev/ttyHS1`, a second reader
    does not get a copy — they race, and both get a corrupted subset. Stop the
    `mavlink` instance on that device first, or read the board from a separate
    machine over a USB-UART adapter.

## Geometry, if you are building your own consumer

For an 8×8 grid with per-axis FoV `fov_deg` (45°), in the sensor's optical frame
(x-right, y-down, z-forward):

```
step  = (fov_deg / 8) * π/180          # angular pitch between zones
ax    = (col - 3.5) * step             # azimuth off optical axis
ay    = (row - 3.5) * step             # elevation off optical axis
dir   = normalize( tan(ax), tan(ay), 1 )
point = (distance_mm / 1000) * dir     # metres, sensor optical frame
```

Then rotate by that channel's mounting bearing from
[Hardware](01-hardware.md#sensor-connectors-8-100-mm-5-pin) to reach the body
frame. The board ships those bearings in its `INFO` message, so a host can read
them rather than hard-coding a second copy.

## Validating placement before flight

With the vehicle disarmed, block one sensor at a time and confirm the obstacle
appears in the expected body direction — in the
[configurator](https://tools.ascendengineer.com), or via `listener
obstacle_distance` by checking which bins drop.

The single most common integration error is mounting rotation. On v2 the nose is
**CH7 (`J8`)**, under the tip of the "A".

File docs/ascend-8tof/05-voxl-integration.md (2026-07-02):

# VOXL Integration (`voxl-ascend-8tof`)

A VOXL-SDK service that bridges the Ascend-8tof board into **voxl-mapper**. It
reads the board's UART ASCII stream, converts every zone into a 3-D point using
the sensor field-of-view model, and publishes **one MPA pipe per channel**.
voxl-mapper consumes each pipe as an independent ToF camera and applies each
sensor's mounting transform from `extrinsics.conf`.

```
                        /run/mpa/tof8_ch0 ┐
ascend-8tof ──UART──►  voxl-ascend-8tof ──┤ one packet per channel ├──► voxl-mapper
                        /run/mpa/tof8_ch7 ┘
```

- **Source:** `voxl-ascend-8tof/` (VOXL-SDK C service, systemd unit).
- **Target host:** VOXL2 / QRB5165 (also builds for qcs6490 / qrb5165-2 / native).

## Why one pipe per channel (v0.1.0)

voxl-mapper's ToF ingestion **discards any point with z ≤ 0 before applying the
per-pipe extrinsic**. The old v0.0.x design merged all 8 sensors into one forward
cloud, so every sensor outside the forward hemisphere was culled — a 360° ring
was impossible. Publishing each channel on its own pipe, in its own +z-forward
optical frame, keeps every point valid and lets voxl-mapper do per-sensor
ray-casting for proper free-space carving.

## Data path

| Stage | Detail |
|---|---|
| **Input** | UART (default `/dev/ttyHS1`, **921600-8N1**). Board prints `--- CH<n> ---` then 8 rows of 8 mm distances (0 = invalid). |
| **Parse** | Header `--- CH<n>` sets the current channel; each subsequent row of 8 ints fills the 8×8 grid; grid timestamped on completion. |
| **Project** | Each zone → a ray from the FoV model at the measured range, in the sensor's own optical frame (**x-right, y-down, z-forward**). Invalid (0 mm) and out-of-range (> `max_range_m`) zones dropped. |
| **Publish** | One packet per channel on `chN_pipe`, `confidences = 255`, rate-limited per channel to `output_rate_hz`. |
| **Place** | voxl-mapper looks up each pipe's extrinsic by name in `/etc/modalai/extrinsics.conf` and transforms the cloud into body frame. |

### Projection math (per zone)

For an 8×8 grid with total per-axis FoV `fov_deg` (default 45°):

```
step   = (fov_deg / 8) * π/180                     # angular pitch between zones
ax     = (col - 3.5) * step                        # azimuth off optical axis
ay     = (row - 3.5) * step                        # elevation off optical axis
dir    = normalize( tan(ax), tan(ay), 1 )          # unit ray, x-right y-down z-forward
point  = (distance_mm / 1000) * dir                # metres, sensor optical frame
```

## Packet formats

voxl-mapper has two ingestion paths with different packet types; `chN_format`
selects which one a channel publishes:

| `chN_format` | Packet type | Magic | voxl-mapper slot | Size |
|---|---|---|---|---|
| `tof2` | `tof2_data_t` (organized 8×8, ray-cast path) | `VOXM` | `tof_pipe_0..3` | ~777 KB/frame |
| `point_cloud` | `point_cloud_metadata_t` (unstructured) | `VOXL` | `depth_pipe_0..3` | ~40 B + 12 B/point |

> Route the wrong format to a slot and voxl-mapper logs
> `invalid metadata, magic number=…`. voxl-mapper has exactly **4 tof + 4 depth
> slots = 8**, so all 8 sensors fit if you split them 4/4 (this is the default).

## Building & packaging

Built inside the `voxl-cross` docker, like every VOXL-SDK project:

```bash
./install_build_deps.sh qrb5165 dev   # once, inside voxl-cross
./build.sh qrb5165                     # or qrb5165-2 / qcs6490 / native
./make_package.sh                      # -> voxl-ascend-8tof_<ver>_arm64.deb
```

Install the `.deb` on the VOXL2, then:

```bash
systemctl enable voxl-ascend-8tof
systemctl start  voxl-ascend-8tof
```

## Configuration — `/etc/modalai/voxl-ascend-8tof.conf`

Created with defaults on first run.

| Key | Default | Meaning |
|-----|---|---|
| `uart_path` | `/dev/ttyHS1` | serial device the board is on (VOXL2 HS UARTs are `/dev/ttyHS0..3`) |
| `uart_baud` | `921600` | must match firmware (see [comms](03-comms-protocol.md#baud-rate-important)) |
| `fov_deg` | `45.0` | total per-axis VL53L8CX FoV |
| `max_range_m` | `4.0` | drop zones farther than this (8×8 is reliable to ~4 m) |
| `output_rate_hz` | `15.0` | per-channel max publish rate |
| `grid_stale_ms` | `200` | drop a channel grid older than this |
| `chN_enable` | `true` (all 8) | include firmware channel N |
| `chN_pipe` | `/run/mpa/tof8_chN` | MPA pipe this channel publishes on |
| `chN_format` | `tof2` for CH2/3/4/7, `point_cloud` for CH0/1/5/6 | packet type; must match the voxl-mapper slot |

> The v0.0.x per-channel `chN_roll/pitch/yaw/x/y/z` keys and the global
> `output_pipe` key are **removed** — the mounting transform now lives in
> `extrinsics.conf`. Delete them from any pre-existing config (the service
> rewrites defaults on first run).

## voxl-mapper wiring

Wire each `chN_pipe` into a `tof_pipe_N` / `depth_pipe_N` slot in
`/etc/modalai/voxl-mapper.conf`, each with its own extrinsic name.
Recommended allocation (forward+sides on the better tof ray-casting path, rear on
depth):

```jsonc
"tof_pipe_0":   "/run/mpa/tof8_ch3", "tof_0_enable": true, "tof_0_rate": 15, "tof_extrinsics_0_name": "tof8_ch3",  // N
"tof_pipe_1":   "/run/mpa/tof8_ch4", "tof_1_enable": true, "tof_1_rate": 15, "tof_extrinsics_1_name": "tof8_ch4",  // NE
"tof_pipe_2":   "/run/mpa/tof8_ch2", "tof_2_enable": true, "tof_2_rate": 15, "tof_extrinsics_2_name": "tof8_ch2",  // NW
"tof_pipe_3":   "/run/mpa/tof8_ch7", "tof_3_enable": true, "tof_3_rate": 15, "tof_extrinsics_3_name": "tof8_ch7",  // E

"depth_pipe_0": "/run/mpa/tof8_ch6", "depth_pipe_0_enable": true, "depth0_rate": 15, "extrinsics0_name": "tof8_ch6",  // SE
"depth_pipe_1": "/run/mpa/tof8_ch5", "depth_pipe_1_enable": true, "depth1_rate": 15, "extrinsics1_name": "tof8_ch5",  // S
"depth_pipe_2": "/run/mpa/tof8_ch1", "depth_pipe_2_enable": true, "depth2_rate": 15, "extrinsics2_name": "tof8_ch1",  // SW
"depth_pipe_3": "/run/mpa/tof8_ch0", "depth_pipe_3_enable": true, "depth3_rate": 15, "extrinsics3_name": "tof8_ch0",  // W
```

## Extrinsics — `/etc/modalai/extrinsics.conf`

For a board mounted flat on top of the FCU with **CH3 facing the drone's nose**,
body frame FRD (X forward, Y right, Z down). Each sensor needs a `body`→`tof8_chN`
entry.

**Convention:** ModalAI's `RPY_parent_to_child` produces a matrix labeled
`R_child_to_parent` — column 2 is the sensor's optical Z (forward) expressed in
body coordinates (verify with `voxl-inspect-extrinsics -p body -c tof8_ch3`).

| CH | Bearing | `T_child_wrt_parent` | `RPY_parent_to_child` (intrinsic XYZ, deg) |
|----|---|---|---|
| CH3 | N (forward) | `[0,0,0]` | `[0, 90, 90]` |
| CH4 | NE | `[0,0,0]` | `[-90, 45, 180]` |
| CH7 | E (right) | `[0,0,0]` | `[-90, 0, 180]` |
| CH6 | SE | `[0,0,0]` | `[-90, -45, 180]` |
| CH5 | S (rear) | `[0,0,0]` | `[90, -90, 0]` |
| CH1 | SW | `[0,0,0]` | `[90, -45, 0]` |
| CH0 | W (left) | `[0,0,0]` | `[90, 0, 0]` |
| CH2 | NW | `[0,0,0]` | `[90, 45, 0]` |

Translation can stay at zeros for first-pass mapping (sensors sit ~3 cm from FCU
center — negligible at meter scale). **Verify each channel empirically:** with
voxl-mapper running, block one sensor at a time and confirm the obstacle appears
in the expected body direction in voxl-portal.

## Debugging

```bash
systemctl stop voxl-ascend-8tof
voxl-ascend-8tof -d                         # parse/publish stats per channel
voxl-ascend-8tof -c                         # create/print config then exit
voxl-inspect-pipes                          # list all pipes and clients
voxl-inspect-tof    tof8_ch3                # tof2 channels (CH2/3/4/7)
voxl-inspect-points tof8_ch0                # point_cloud channels (CH0/1/5/6)
voxl-inspect-extrinsics -p body -c tof8_ch3 # verify resolved R_child_to_parent
```

## Version history

- **v0.1.0** — one MPA pipe per channel (breaking); `chN_format` selectable
  (tof2/point_cloud); mounting transform moved to `extrinsics.conf`; all 8
  channels on by default; `max_range_m` 6→4, `grid_stale_ms` 500→200.
- **v0.0.1** — initial release; merged all channels into a single `tof2` cloud on
  `/run/mpa/tof`.

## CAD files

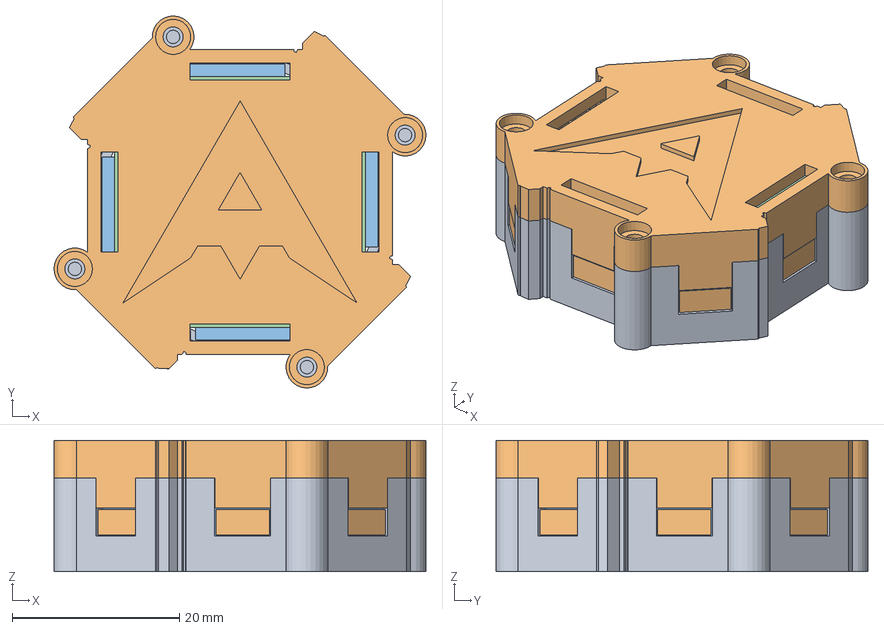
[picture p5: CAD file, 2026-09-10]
docs/ascend-8tof/downloads/case/tof8_v2_COMPLETE_assembly.step
44.5 x 44.5 x 15.7 mm

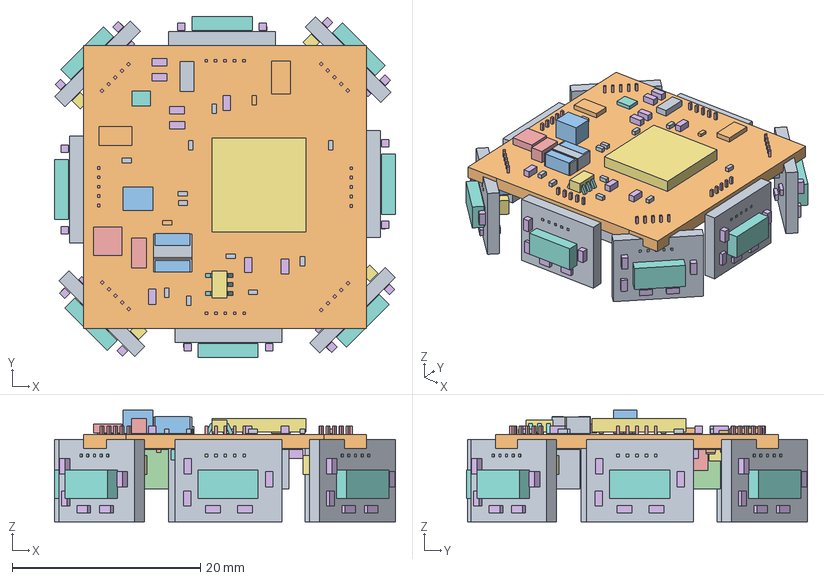
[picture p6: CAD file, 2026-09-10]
docs/ascend-8tof/downloads/case/tof8_v2_electronics.step
36.2 x 36.2 x 11.9 mm

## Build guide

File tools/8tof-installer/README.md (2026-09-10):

# 8TOF installer source

These files are the installer source packaged in the 2026.09.10-10hz10ms
firmware ZIP under `docs/ascend-8tof/downloads/firmware/`.
Install from the complete extracted ZIP: these source files alone lack the
firmware and its manifest. Public instructions are in
`docs/ascend-8tof/08-install-firmware.md`.

When publishing another version, update the versioned ZIP and checksum, then
copy its installer files here so the downloadable and reviewable versions match.
Do not include per-board backups or local device logs in this repository.

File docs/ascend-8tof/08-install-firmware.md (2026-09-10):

# Install firmware

Install a prebuilt image on the **horizontal v3 STM32H563RGT6 carrier with
eight v2 VL53L8CX sensor boards**. This is the carrier used in the Ascend-8tof v2
system described here. The installer programs the sensor board, not the flight
controller. No firmware compiler or source checkout is required.

## Download

| Package | Profile | Status |
|---|---|---|
| [Firmware and installer ZIP](downloads/firmware/2026.09.10-10hz10ms/ascend-8tof-horizontal-v3-10hz10ms-2026-09-10.zip) | **8×8 · 10 Hz · 10 ms**, `AVOID=cp`, 180° zone orientation | **Bench candidate — hardware verification pending** |
| [ZIP SHA-256 checksum](downloads/firmware/2026.09.10-10hz10ms/ascend-8tof-horizontal-v3-10hz10ms-2026-09-10.zip.sha256) | Verify the complete download | Version `2026.09.10-10hz10ms` |

Read the [release notes and validation status](09-firmware-release-notes.md)
before installing. The ZIP contains the firmware, Python installer, launchers,
OpenOCD configuration, manifest, checksums, and offline instructions. Extract
**all files** into one folder; do not run the installer directly from the ZIP.

!!! note "Validation status"
    Firmware compilation, regression tests, and 15 installer tests passed.
    The live installation attempt stopped before any write because no ST-Link
    was connected. This exact release has not yet completed hardware readback;
    range and input power are unmeasured. Windows/Linux hardware installation
    also remains unverified.

## Prerequisites

- [Python 3.9 or newer](https://www.python.org/downloads/).
- An **ST-Link** programmer with its USB drivers or Linux USB permissions
  configured. An FTDI UART cable displays sensor data; it does not flash this
  board.
- **ST OpenOCD with STM32H5 support**, including `interface/stlink-dap.cfg` and
  `target/stm32h5x.cfg`. Use the executable and scripts from the same ST
  distribution. ST OpenOCD is available with
  [STM32CubeIDE](https://www.st.com/en/development-tools/stm32cubeide.html)
  or from [ST's source](https://github.com/STMicroelectronics/OpenOCD).
  Generic OpenOCD 0.12 packages may lack STM32H5 support.
- The complete extracted release ZIP. Python, OpenOCD, and USB drivers are
  installed separately; the installer does not download them automatically.

The installer targets Windows, macOS, and Linux using Python's standard
library. The ST OpenOCD build used for earlier board flashing was
`0.12.0+dev-00635-g0a084c293`.

## Connect the board

Work on the bench with the vehicle disarmed and propellers removed. Supply
**regulated 5 V through J5 pin 1**, with ground on pin 4. See
[Power](02-power.md) and the [connector photos](01-hardware.md#connectors-pinouts).

Connect the ST-Link to J6:

| J6 pin | Board signal | ST-Link signal |
|---|---|---|
| 1 | GND | GND |
| 3 | SWDIO | SWDIO |
| 4 | SWCLK | SWCLK |
| 6 | +3V3 | Target-voltage sense / VTref |

J6 pin 6 is a **voltage reference**, not an input for a programmer's power
output. Check the pinout of your particular ST-Link. SWO and RESET are not
required by this installer; it uses a software reset. Connect only one ST-Link,
or select a probe with `--serial`. Close other debugger/programmer sessions.

## Run the installer

Open a terminal in the extracted folder and check package integrity first:

=== "macOS / Linux"

    ```sh
    python3 install.py --check
    sh install.sh
    ```

=== "Windows"

    ```bat
    py -3 install.py --check
    .\install.cmd
    ```

If OpenOCD is not found, pass its paths explicitly. Replace the example paths
with the executable and scripts in your ST installation:

=== "macOS / Linux"

    ```sh
    python3 install.py --board horizontal-v3 \
      --openocd "/path/to/tools/bin/openocd" \
      --scripts "/path/to/scripts"
    ```

=== "Windows"

    ```bat
    py -3 install.py --board horizontal-v3 --openocd "C:\path\to\openocd.exe" --scripts "C:\path\to\scripts"
    ```

STM32CubeIDE may put scripts in the debug plugin's
`resources/openocd/st_scripts` folder, separate from the executable in the
external-tools OpenOCD plugin. `OPENOCD` and `OPENOCD_SCRIPTS` environment
variables can supply the same paths.

The installer checks the image, identifies the MCU and flash layout, and shows
the unique board ID. Confirm that the physical board is the **horizontal v3**:
a matching MCU cannot identify a PCB revision. Type **`INSTALL`** to continue.
Automated bench runs can add `--yes`.

The installer then:

1. Saves a complete **1 MiB flash backup** in a new local directory.
2. Programs and verifies the firmware region.
3. Resets the board and waits for startup.
4. Checks all eight sensors for autonomous mode, 8×8 resolution, 10 Hz, and 10 ms.
5. Checks that saved mask bytes are unchanged and verifies the installed image's
   SHA-256 checksum by reading it back.

Success requires all eight sensors to start with the expected settings. Backups,
logs, and `result.json` are stored under **`Ascend8TOF/backups` in your home
folder**. Use `--backup-dir PATH` to choose another location. Keep these files
with that board; they are not part of the public download.

## Verify the output

Open the [configurator](https://tools.ascendengineer.com) in Chrome, connect the
FTDI adapter at **921600 baud**, and check all eight channels. Move an object
in front of each sensor. The tip of the A marks the nose: **CH7/J8**.

The dashboard's packet/frame rate may exceed 10 Hz because the MCU polls more
frequently. It is not the rate of fresh measurements from each sensor.

This release reports **unknown** for weak, missing, masked, expired, or
unmeasured directions. PX4 may restrict motion into those directions. Do not
set `CP_GO_NO_DATA` merely to hide missing measurements. Valid close obstacles
are retained; use deliberate zone masks for enclosure and airframe returns.
See [Communications](03-comms-protocol.md#obstacle_distance-field-values).

## Troubleshooting and rollback

| Problem | Next step |
|---|---|
| OpenOCD or scripts not found | Supply the explicit paths above; confirm `stm32h5x.cfg` and `stlink-dap.cfg` exist. |
| No ST-Link or target | Check USB enumeration, board power, VTref, ground, cable orientation, drivers/permissions, and other debugger sessions. |
| Unexpected MCU, flash layout, or protection | Stop and check the board. The installer does not unlock devices, change option bytes, or perform a mass erase. |
| Sensor verification failed | Read `verify-sensors.log`. Programming may have succeeded while a sensor was disconnected; check all eight boards and their power, then retry. |
| Saved mask or image readback mismatch | Keep the full backup and logs; do not treat the installation as verified. |

For rollback, retain that board's `before-flash.bin` and logs. A full restore
also restores its original mask. Use an STM32H563-capable programmer to write
the backup at `0x08000000`, verify, and reset. Do not use another board's backup
or erase option bytes. The supplied installer accepts only its checksummed
release image.

Bench installation checks do not establish outdoor range, braking distance,
or readiness for flight. Configure and validate the flight controller separately
using the [integration guide](05-integration.md).

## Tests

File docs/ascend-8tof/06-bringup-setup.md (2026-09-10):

# Bring-up & Setup Guide

Boards in a box → a working obstacle sensor on your vehicle. Boards ship
**pre-flashed** with your chosen [firmware variant](04-firmware.md); the build
and flash steps here are only needed if you are changing it.

## 0. What you need

- Ascend-8tof v2 carrier board + 8 TOF sub-boards.
- A **regulated 5 V** supply for `J5` pin 1 — **not** a flight battery, see
  [Power](02-power.md).
- A 921 600-capable **USB-UART adapter** for bench work. Its 5 V/VCC can power
  the board through `J5` pin 1, so one 4-wire lead does power and data.
- An **ST-Link** on `J6` only if you need to reflash.
- Chrome, for the [configurator](https://tools.ascendengineer.com).

## 1. Assemble

[Case and assembly STEP downloads](10-case-files.md) are available for CAD
reference and enclosure fit checks.

Plug each sub-board into its sensor port. The port fixes the channel, and the
channel fixes the bearing:

| Channel | Port | Direction | Channel | Port | Direction |
|---|---|---|---|---|---|
| **CH7** | **`J8`** | **FRONT / nose** | CH3 | `J1` | back |
| CH0 | `J4` | front-right | CH4 | `J9` | back-left |
| CH1 | `J3` | right | CH5 | `J10` | left |
| CH2 | `J2` | back-right | CH6 | `J7` | front-left |

Seat every connector fully before powering. Mount the unit with the **tip of the
"A" facing the vehicle nose** — that is CH7.

## 2. Power and verify

1. Wire the adapter to `J5`: **board TX (pin 3) → adapter RX**, **adapter TX →
   board RX (pin 2)**, GND↔GND, and 5 V to pin 1 if powering this way.

    Both directions must be connected. The point cloud is gated on the board
    hearing from a host (see
    [Communications](03-comms-protocol.md#why-a-passive-listener-sees-only-mavlink)),
    so TX-only wiring will never show you a cloud.

2. Open the [configurator](https://tools.ascendengineer.com) in Chrome and
   connect, **or** run:

    ```bash
    python3 tools/tof8-stream.py          # live 8×8 grids
    python3 tools/tof8-poll.py            # link health, which channels range
    ```

3. Wave a hand ~30 cm from the nose sensor. **CH7**'s grid should drop to ~300 mm.
   If a different channel lights up, the unit is not mounted nose-forward.

**Sanity checks**

- The onboard LED is a **power-good indicator only** — rails are up. It says
  nothing about sensors or data.
- Zones with no return read as no data, **not** "obstacle at 0 mm".
- A missing channel points at that sub-board or its connector — but read the
  next section before concluding the mux is bad.

## 3. Reflashing (optional)

To use the prebuilt 10 Hz / 10 ms bench candidate, follow
[Install Firmware](08-install-firmware.md). That package includes its own
installer; its hardware verification is still pending. The source-repository
workflow below applies when building a different firmware version yourself.

```bash
AVOID=cp BOARD=horiz3 ./tools/flash-board.sh
```

Expect `sensors : 8/8` / `ALL 8 CHANNELS OK`. If it reports `0/8`, **power-cycle
the board and re-check** before believing it:

```bash
./tools/read-sensors.sh     # reads a running board without resetting it
```

A reset does not clear the multiplexer's channel latch, so a bus jammed before
flashing stays jammed through the flash.

## A sensor that jams the bus

This failure mode is worth understanding because **the error message points at
the wrong part**.

A VL53L8CX that holds SDA low drags down the whole shared bus the instant the
multiplexer connects it. From the MCU's side that is indistinguishable from a
dead multiplexer, so bring-up reports *every* channel as
`mux never answered (check U2)` — including seven healthy ones.

Firmware cannot recover from it. Clearing the TCA9548A's channel latch requires
a bus transaction, and the bus is exactly what is jammed; `U2`'s `RESET` is only
pulled up by `R6`, not driven by a GPIO. **Only a power cycle clears it.**

### Locating the bad sensor

```bash
# 1. ascending walk
make BOARD=horiz3 AVOID=cp DIAG=1 && DIAG=1 ./tools/flash-board.sh
#    POWER-CYCLE the board, then:
DIAG=1 ./tools/read-diag.sh

# 2. descending walk
make BOARD=horiz3 AVOID=cp DIAG=1 DIAGDIR=down && DIAG=1 DIAGDIR=down ./tools/flash-board.sh
#    POWER-CYCLE again, then:
DIAGDIR=down ./tools/read-diag.sh
```

The walk samples SCL/SDA **before anything drives them**, then enables one
channel at a time:

```
cold SCL   : HIGH (idle, healthy)
cold SDA   : HIGH (idle, healthy)
mux @ 0x70 : ACK
first bad  : CH4

  CH0 (J4) front-right   clean, sensor ACKed at 0x29
  ...
  CH4 (J9) back-left     SDA PULLED LOW  <-- this channel jams the bus
```

Reading the result:

- **cold SDA LOW** — no sensor can be responsible; the multiplexer comes out of
  reset with every channel disconnected. The fault is on the main segment: the
  MCU pin, `R3`, `U2`'s upstream side, or a short.
- **cold SDA HIGH** — the bus is fine at rest, and the walk names the culprit.

!!! warning "Run the walk in both directions"
    Once a channel jams the bus, every later `select` silently does nothing and
    the multiplexer stays latched on the culprit — so channels *after* it are
    **indeterminate, not bad**. The tool labels them as such. Only channels that
    fail in both directions are genuinely bad.

### Keeping the board usable

```bash
make BOARD=horiz3 AVOID=cp EXCLUDE=4 && EXCLUDE=4 ./tools/flash-board.sh
```

The excluded channel is never selected, so the remaining seven work normally.
This is a stopgap — replace the sensor when you can.

## Other failure signatures

| Symptom | Meaning |
|---|---|
| `mux never answered` on **all 8** | Usually one sensor jamming the bus, not a dead `U2`. Run the walk above. |
| `firmware download failed` on one channel | Sensor ACKs at `0x29` and passes `is_alive()` but cannot take the ~85 KB firmware load. Points at the part or a marginal joint, not the bus. Swap that sensor with a known-good one to confirm. |
| `sensor did not answer` on one channel | Nothing on that connector — check the sub-board and seating. |
| `start_ranging failed` | Usually supply current — check the 5 V rail under load. |

A quick way to separate a bad sensor from a bad board position: **swap the
suspect sub-board with a known-good one.** If the fault follows the part, replace
it; if it stays on the connector, it is board-side.

## 4. Integrate

See [Integration](05-integration.md) for the PX4 collision-prevention path
(`AVOID=cp`, the default) and the VOXL2 worked example.

## Troubleshooting quick-reference

| Symptom | Likely cause / fix |
|---|---|
| MAVLink visible, no point cloud | Expected. The cloud is gated — you must send a keepalive. Use `tof8-stream.py` or the configurator. |
| Nothing at all on the UART | Baud (**921 600-8N1**), or board TX → adapter RX reversed. |
| Cannot open the port | Something else owns it — configurator tab, `screen`, or `mavlink-router`. On a VOXL2, PX4's `mavlink` owns `/dev/ttyHS1`. |
| Configurator will not connect | Web Serial needs HTTPS and Chrome. |
| `0/8` right after flashing | Power-cycle and re-check with `read-sensors.sh` — a reset does not clear the mux latch. |
| Obstacle appears in the wrong direction | Unit not mounted nose-forward. On v2 the nose is **CH7 (`J8`)**, not CH3. |

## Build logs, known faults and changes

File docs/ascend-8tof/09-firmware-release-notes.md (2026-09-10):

# Firmware release notes

## 2026.09.10-10hz10ms — bench candidate

[Download and install](08-install-firmware.md) this candidate for the horizontal
v3 STM32H563RGT6 carrier with eight v2 VL53L8CX sensor boards.

| Setting | Value |
|---|---|
| Sensor grid | 8×8 per sensor; 512 zones total |
| Sensor rate | **10 Hz per sensor** |
| Sub-integration | **10 ms**, four per 8×8 frame |
| Ranging mode | Autonomous |
| Output | `AVOID=cp`: MAVLink `OBSTACLE_DISTANCE` at 10 Hz |
| Zone orientation | 180°, matching the fitted v2 sub-boards |
| Host UART | 921600 baud, 8N1 |

### Measurement handling

Weak, inconsistent, and no-target readings now leave their direction
**unknown**. A successful sensor read, an unmasked field of view, or a missing
echo no longer declares clearance to 4 m. Masked returns, excluded floor/ceiling
returns, out-of-range readings, and gaps between measured angular directions
also remain unknown.

Accepted status 5 or 9 measurements provide obstacle distances. Status 9 can
represent a merged target; it is accepted as an obstacle, not as proof of
clearance. Target-count output is enabled so a zone without a target is marked
as no data rather than trusting a leftover distance/status.

**Close obstacles below 50 cm are retained.** The advertised minimum is 2 cm;
a positive reading below that is reported at the minimum rather than discarded.
Use deliberate zone masks for enclosure and airframe returns.

The avoidance path keeps each sensor's latest frame between polls and expires
it **200 ms after its successful polling pass**, including when acquisition
stalls. New invalid readings replace old valid readings immediately. These
host timestamps do not compensate for exposure time, transport delay, or
vehicle motion. The raw browser protocol retains its original per-poll fresh
sensor bitmap.

!!! warning "Unknown directions can restrict movement"
    PX4 Collision Prevention may restrict movement into open sky or poorly
    measured directions. Do not enable `CP_GO_NO_DATA` merely to hide missing
    measurements. This release does not claim continuous calibrated coverage
    between individual zone rays or guaranteed 4 m visibility outdoors.

### Power and timing

Each complete 8×8 frame uses four sub-integrations. The candidate has a 100 ms
frame interval and 40 ms of exposure per frame: **40% calculated exposure duty**.
This is not total board power.

| Profile | Frame interval | Exposure per frame | Exposure duty |
|---|---:|---:|---:|
| Earlier 15 Hz / 5 ms experiment | 67 ms | 20 ms | 30% |
| **This candidate: 10 Hz / 10 ms** | **100 ms** | **40 ms** | **40%** |
| Earlier 15 Hz / 10 ms profile | 67 ms | 40 ms | 60% |

Longer exposure can improve weak-target detection, with less frequent updates
than 15 Hz / 5 ms. It does not automatically correct calibration errors.
Compare input watts, missed detections, and measurement age with the same
scene, supply, and peripherals. See [Power](02-power.md#choosing-a-ranging-profile).

### Installation and saved settings

Startup and sensor recovery use shared configuration/readback checks for mode,
rate, resolution, and integration. The packaged installer checks those values
on all eight sensors after programming. Saved zone masks keep their existing
layout and orientation, and the installer checks their bytes before/after.

### Validation status

**Passed:** ARM compilation/link; obstacle-status, close-range, mask, angular-gap,
freshness/expiry, and timer-wrap regressions; existing protocol and orientation
tests; 15 installer tests; package-integrity checks.

**Pending:** an end-to-end hardware installation and all-eight-sensor readback
of this exact release. The installation attempt stopped during identification,
before backup or flash, because the ST-Link was absent from USB. Earlier 5 ms
flashes do not validate this candidate. Windows/Linux hardware installation,
power, range, optical calibration, and recovery fault injection remain
unverified.

The ZIP includes `VALIDATION.md`, offline installation instructions, the release
manifest, checksums, and third-party notices. It is a bench candidate, not a
flight-validation result.

References: [ST integration timing and target-status interpretation](https://www.st.com/content/st_com/en/technical-documents/UM3109.html),
[MAVLink distance and unknown values](https://mavlink.io/en/messages/common.html#OBSTACLE_DISTANCE).

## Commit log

2026-07-02 Initial docs: Ascend-8tof system documentation site
    Complete documentation for the Ascend-8tof 360° VL53L8CX time-of-flight
    obstacle-sensing system, sourced from the KiCad schematics/BOM, the
    STM32H563 firmware (ascend-tof8), and the VOXL companion (voxl-ascend-8tof):
    - Hardware overview (boards, MCU pinmap, mux, connectors & pinouts)
    - Power & voltage ranges (input range, both bucks, rails, protection)
    - Communications & protocols (I2C bus, UART wire format, MPA pipes)
    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
    [main-board-bom.csv, tof-board-bom.csv]
2026-07-02 Restructure into a multi-product docs hub
    Turn the site into an Ascend Engineering documentation hub so it can hold
    docs for more hardware/software, with ascend-8tof as the first product
    section:
    - Move the ascend-8tof docs into docs/ascend-8tof/ (git mv preserves history);
    its former overview becomes the section landing page.
    - Add a top-level docs/index.md hub with product grid cards.
    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
2026-07-02 Reframe as host-agnostic: VOXL2 is one example, not the requirement
    The board's only external interface is a plain ASCII UART stream; any flight
    controller or onboard computer can consume it. VOXL2 + voxl-mapper is just the
    worked example we ship a plugin for. Updated across the 8tof docs:
    - Rename 05-voxl-integration.md -> 05-integration.md; lead with a host-agnostic
    overview + generic integration recipe (FoV model, ArduPilot/PX4/ROS/MCU notes),
    then keep the full VOXL2 + voxl-mapper walkthrough as "Example".
    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
2026-07-02 Document the ACO collision-avoidance firmware variant (beta)
    The board has a second firmware (branch ascend-tof8-aco): a FreeRTOS-based
    on-board collision-avoidance build that speaks MAVLink v2 straight to a flight
    controller, no companion computer. Documented from the branch source:
    - Firmware page: lead with a two-variant table (default sensor-stream vs ACO);
    add a full "ACO Firmware — onboard collision avoidance (beta)" section covering
    the FreeRTOS architecture, the OA algorithm (velocity-scaled safety cuboid),
    the MAVLink interface (OBSTACLE_DISTANCE #330 TX / ODOMETRY RX, 115200, comp id
    196), default tuning params, tasks/LED, build/flash, and beta limitations.
    - Comms: scop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
2026-07-02 Sanitize docs: remove hardware/firmware recreation detail
    Strip anything that would let a third party clone the board or firmware,
    keeping what an integrator actually needs (voltage/current ranges, UART
    layout, what each firmware does and how to use it). Per product decision,
    the VL53L8CX sensor and STM32H5 MCU family names are kept; all supporting
    component detail is removed.
    - Remove the entire bom/ folder (full BOM = recreation blueprint).
    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
    [main-board-bom.csv, tof-board-bom.csv]
2026-07-02 Add example ASCII output capture to the UART protocol page
2026-07-02 Correct LED description: onboard LED is power-good only
    The board's LED is a hardware power-good indicator, not a firmware-driven
    status LED. Remove the incorrect ACO status-LED blink-pattern table and note
    in bring-up that the LED only indicates power/rails, not data or collision state.
2026-07-02 Document J1 as a wide DC input (5 V up to a 6S LiPo)
    The 2-pin J1 feeds a wide-input regulator; with the USB-protection IC DNP,
    the input accepts 5 V up to a 6S LiPo (~25 V), regulated to the sensor rails
    on-board. Update the power page and all 'single 5 V input' references across
    the overview, integration, and bring-up guide.
2026-07-02 Document powering the board via the UART 5V pin (J7 pin 1)
    J7 pin 1 is a 5V power INPUT (diode-OR'd onto VIN via D3), not an output —
    correct the earlier 'output/do not back-feed' note. You can power the board
    from a USB-UART adapter's 5V. Add it as a third input alongside J1 and USB-C,
    note the inputs are diode-OR'd, and mention it in the bring-up guide.
2026-07-02 Restore board photo (smaller, centered) and dimensions table
    Re-add the content from after the UART-5V commit that got dropped during the
    deploy troubleshooting. Photo is now scaled down in a padded, centered figure;
    dimensions table restored.
2026-07-02 Switch deploy to gh-pages branch method (mkdocs gh-deploy)
    Replace actions/deploy-pages (which kept jamming the Pages deployment queue)
    with mkdocs gh-deploy pushing the built site to the gh-pages branch. Pages
    now serves from that branch statically (.nojekyll). Robust, no deploy queue.
2026-07-02 Switch deploy back to GitHub Actions method (deploy-pages)
    Revert to the standard Actions-based Pages deploy (build + upload-pages-artifact
    + deploy-pages). Requires Pages Source = 'GitHub Actions'.
2026-07-12 docs(8tof): add Obstacle Avoidance (setpoint streaming + PX4 fusion) page
    Explains the onboard-VFH setpoint-streaming approach: the board computes the
    evasive velocity and streams SET_POSITION_TARGET to a forked PX4 that fuses it
    into Position and Mission mode (vs. the ACO OBSTACLE_DISTANCE / Collision
    Prevention path). Covers the data flow, why the PX4 fork, flight behavior per
    mode, the EAV_EN/EAV_TIMEOUT config, and the Gazebo digital-twin validation.
    Adds it to the nav and the 8tof doc map.
2026-09-02 docs(8tof): document v2 (horizontal board), replacing the v1 pages
    v2 is a different PCB from the 40x40 mm vertical board, not a revision of it,
    and almost nothing in the existing pages survived the change. Three of the
    errors were actively dangerous to anyone applying v1 knowledge to v2 hardware:
    * Power. v1 accepted 5 V to a 6S LiPo. v2's J5 pin 1 feeds a TLV75733 3.3 V
    LDO through nothing but a series Schottky (D2, reverse-polarity only) --
    absolute maximum 6 V. The docs told integrators to wire a flight battery to
    a part that dies above 6 V. v2 is 5 V only, and the page now says why and
    notes that there is no overvoltage protection at all.
    * Orientation. The docs sai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
2026-09-02 docs(8tof): add the v2 board photo
    Replaces the pending-photo placeholder with the real figure. Downscaled to
    1000 px and re-encoded as JPEG (1.2 MB -> 172 KB), since the page loads it at
    420 px and the original was a full-resolution screenshot.
    Caption points out what the photo is actually useful for: the tip of the "A"
    marks the nose, so the sensor behind the slot below it is CH7 (J8) -- the
    single most common integration mistake is mounting the unit rotated.
    Still strict-clean.
2026-09-02 docs(8tof): drop the version-comparison framing, add weights and a connector photo
    The pages were written as a migration guide -- repeatedly contrasting this board
    with the previous one -- which is noise for anyone reading them as the
    documentation for the product in front of them. Removed every such comparison so
    the docs simply describe this board.
    The safety warnings stay, they just no longer explain themselves by reference to
    older hardware:
    * The 5 V limit is now stated as a property of the input stage (a 3.3 V LDO
    with a 6 V absolute maximum and no overvoltage protection ahead of it),
    rather than as a change from a wide-input predecessor.
    * The channel map's "how this was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
2026-09-10 docs: add 8TOF firmware installer and case downloads
    [oa_pcb_tof8_v2_assembly.stl, tof8_v2_COMPLETE_assembly.step]
2026-09-10 docs: replace assembly STL with electronics STEP and clarify validation
    [oa_pcb_tof8_v2_assembly.stl, tof8_v2_electronics.step]
